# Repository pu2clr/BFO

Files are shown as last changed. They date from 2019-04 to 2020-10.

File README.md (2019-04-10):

# Simple BFO with si5351 controlled by Arduino

## Table of contents

1. [Introduction](https://github.com/pu2clr/BFO#introduction)
1. [Components](https://github.com/pu2clr/BFO#components)
1. [Schematic](https://github.com/pu2clr/BFO#this-bfo-interface)
1. [BFO interface](https://github.com/pu2clr/BFO#bfo-interface)
1. [Arduino pins and  Encoder, Step, Reset BFO and Turt On or Off commands](https://github.com/pu2clr/BFO#arduino-pins-and--encoder-step-reset-bfo-and-turn-on-or-off-commands)
1. [SI5351 Calibration](https://github.com/pu2clr/BFO#si5351-calibration)
1. [References](https://github.com/pu2clr/BFO#references)
1. [Videos about this project](https://github.com/pu2clr/BFO#videos-about-this-project)

## Introduction

The Si5351 is an I2C configurable clock generator that is very appropriate for receivers and transceivers projects in amateur radio applications. It is also suited for replacing crystal oscillators. It has three outputs that you can get three distinct frequencies at the same time. A great feature of the Si5351A is the possibility of using it with a microcontroller or platform like Arduino, PIC family and others. This small project is about a BFO that you can control the output of the Si5351A by using the Arduino Micro (Atmega32u4).  The BFO tested here ocilates from 452KHz to 458KHz. However, you can change this range for other between 8Kz to 160MHz. Click [here](https://youtu.be/AG9XZ8bdaNM) to watch a video about this BFO.

See also the similar project ["VFO and BFO with Si5351 and OLED,  controlled by Arduino (Micro)"](https://github.com/pu2clr/VFO_BFO_OLED_ARDUINO) 

### Using this BFO to listening to 15 meters ham radio station on USB mode

The first real test with this BFO project was made with a commercial radio that does not have SSB support. 

The Redsun RP-2100 is a multi-band commercial radio. It has no SSB internal support. However, it has an IF AM output that allows the user to connect a BFO or a Down-Converter (455 KHz to 12 KHz) to provide SSB, DRM and other modes. The photos bellow show the radio and BFO setup. You can also watch the video "[BFO with SI5351 and Arduino test with REDSUN RP2100](https://youtu.be/AG9XZ8bdaNM)".

#### Photo one
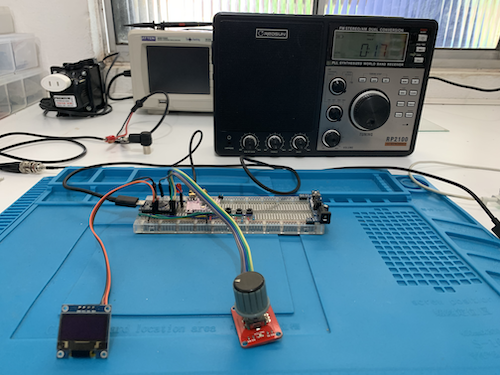
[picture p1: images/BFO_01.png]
Photo One


#### Photo two
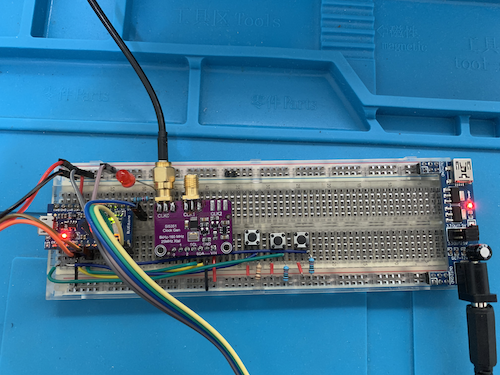
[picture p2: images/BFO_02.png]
Photo Two


#### Photo three
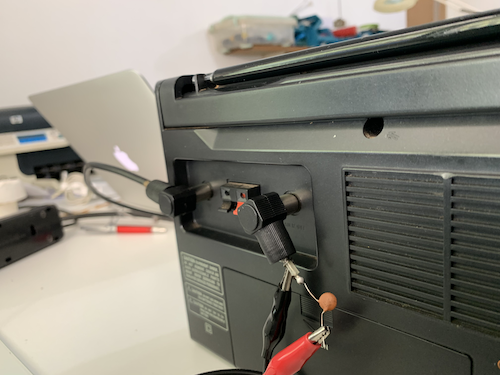
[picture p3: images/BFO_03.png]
Photo Three


## Components

- AZDelivery 1 x OLED Display Arduino 128 x 64 Pixels White 0.96 Inch I2C IIC Module for Arduino. This project uses the [Text only Arduino Library for SSD1306 OLED displays](https://github.com/greiman/SSD1306Ascii) Arduino library.
- Adafruit Si5351A Clock Generator Breakout Board - 8KHz to 160MHz. This project uses the [Si5351 Library for Arduino](https://github.com/etherkit/Si5351Arduino).
- One regular encoder.
- Three regular Push Button.
- Two 10nF ceramic capacitor
- Six 10K resistor
- One 1K resistor  
- Arduino Micro ([Atmega32u4](https://www.microchip.com/wwwproducts/en/ATmega32u4))

## BFO interface

The user can control the BFO  by using tow buttons and an encoder. 

- The __Step button__ changes the increment and decrement step. It can be 10Hz, 50Hz or 100Hz. The BFO can oscilate from 452KHz to 458KHz. You can change this range and frequency if necessary. 
- The __Reset VFO button__ sets the  BFO to central frequency (455KHz);
- The __Turn On/Off BFO button__  turns on or off the BFO. If it is pressed, alternates On and off. BFO off means no output signal.   

## Schematic

The schematic was built by using [Fritzing](http://fritzing.org/home/) Software, an open-source software tools to design circuits. See folder [schematic](https://github.com/pu2clr/BFO/tree/master/schematic).

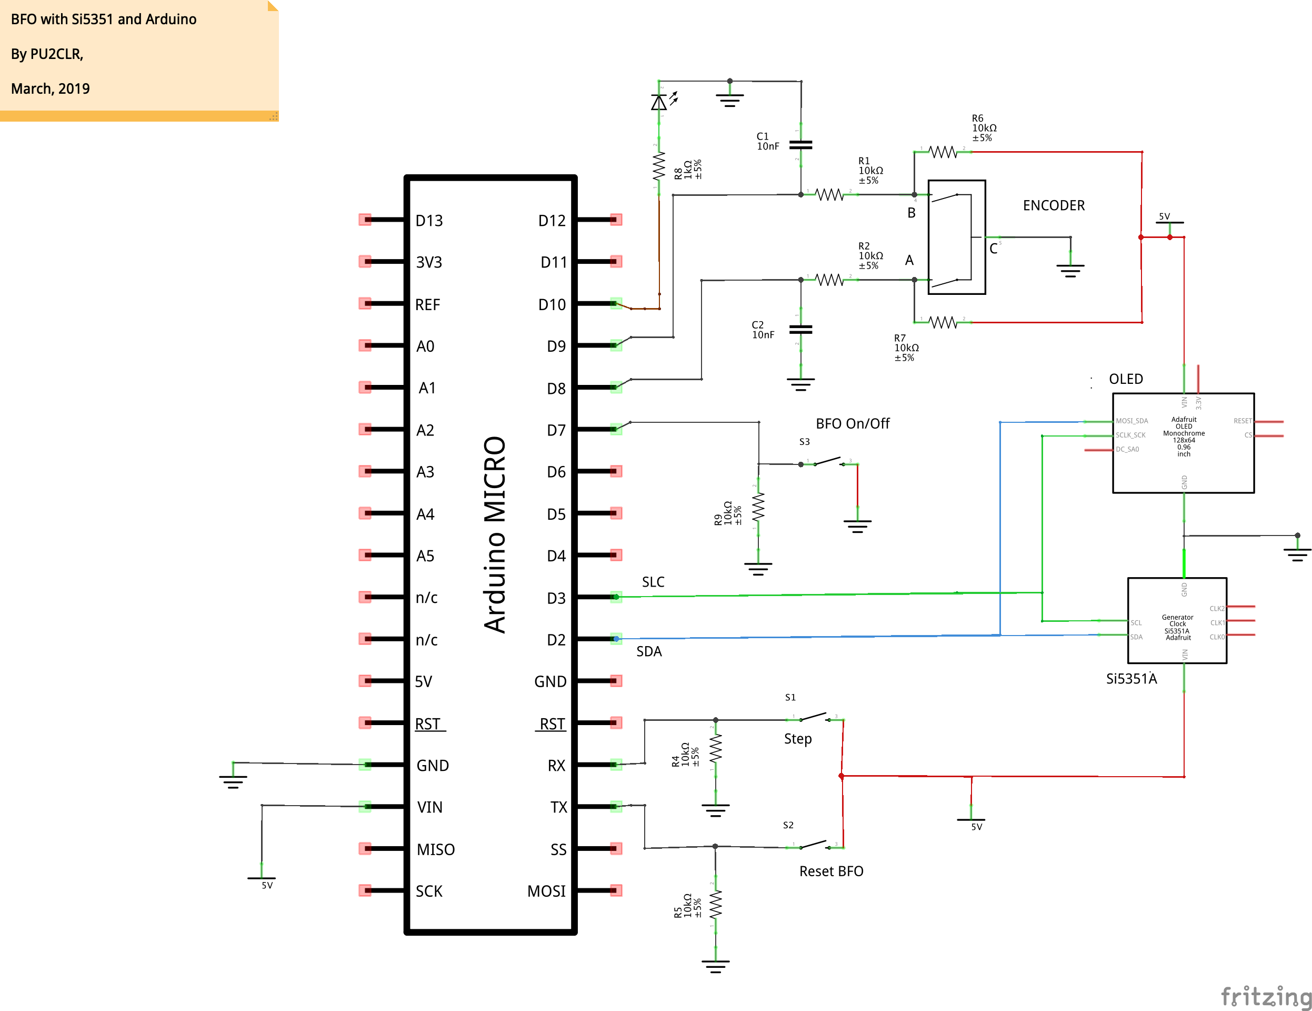
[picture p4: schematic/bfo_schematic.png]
BFO schematic
 

## Arduino pins and  Encoder, Step, Reset BFO and Turn On or Off commands

This section shows some aspects of the BFO [Arduino sketch](https://github.com/pu2clr/BFO/blob/master/source/si5351_bfo.ino) implementation. 

The pins for encoder and push buttons are defined bellow. If you need to change some push button pin, you should be aware that the push buttons are connected to  pins with external interrupts support. On Atmega32u4 you can use the pins 0,1,2,3 and 7, on 328-based (Nano, Mini, Uno) you can use the pins 2 and 3.

The short code below is part of the [Arduino sketch](https://github.com/pu2clr/BFO/blob/master/source/si5351_bfo.ino) and shows the enconder and push buttons setup.

```cpp
#define ENCODER_PIN_A 8 // Arduino  D8
#define ENCODER_PIN_B 9 // Arduino  D9

#define BUTTON_STEP 0   // Control the frequency increment and decrement
#define BUTTON_RST 1    // Set the frequency to central position
#define BUTTON_ON_OFF 7 // Turn BFO ON or OFF
```

The short code below shows the BFO frequency setup.

```cpp
// BFO range for this project is 4520KHz to 458KHz. The central frequency is 455KHz. 
#define MAX_BFO     45800000LU    // BFO max. frequency
#define CENTER_BFO  45500000LU    // BFO center frequency
#define MIN_BFO     45200000LU    // BFO min. frequency
```

The unit of frequency is 0.01Hz (1/100 Hz). See [Etherkit Library](https://github.com/etherkit/Si5351Arduino). 

You might need a different BFO frequency. If you want to modify the central frequency of BFO to 10MHz (for example), just change the lines below.

```cpp
#define MAX_BFO     1100000000LU   // BFO max. frequency (11MHz)
#define CENTER_BFO  1000000000LU   // BFO center frequency (10MHz)
#define MIN_BFO      990000000LU   // BFO min. frequency (9MHz)
```

The buttons were implemented by using Arduino interrupts resource. The code bellow shows it. 

```cpp
// Will stop what Arduino is doing call the function associated to the button
attachInterrupt(digitalPinToInterrupt(BUTTON_STEP), changeStep, RISING); // whenever the BUTTON_STEP is pressed call changeStep
attachInterrupt(digitalPinToInterrupt(BUTTON_RST), resetBfo, RISING);    // whenever the BUTTON_RST is pressed  call resetBfo
attachInterrupt(digitalPinToInterrupt(BUTTON_ON_OFF), bfoOnOff, RISING); // whenever the BUTTON_ON_OFF is pressed  call bfoOnOff
```

## SI5351 Calibration

You might need calibrate your si5351 to get more precision during signal generation. To do that you can use the si5351_calibration.ino sketch that comes with [the Si5351 library for Arduino](https://github.com/etherkit/Si5351Arduino). Click [here](https://github.com/etherkit/Si5351Arduino#calibration) to see more about si5351 calibration. You can also try watch [this Portuguese video](https://youtu.be/BJ83uvDcfIo) that show how to calibrate the si5351. Another video about si5351 calibration can be watch [here (Homebrew 80/40m SSB/CW Rig - #7a Si5351 Calibration)](https://youtu.be/fJ_3z2IAjKg).

The line code bellow shows the correction factor found during this project. 

```cpp
// Change this value bellow  (CORRECTION_FACTOR) to 0 if you do not know the correction factor of your Si5351A.
#define CORRECTION_FACTOR 80000 // See how to calibrate your Si5351A (0 if you do not want).
```

if you do not want calibrate, set CORRECTION_FACTOR to 0 as shown bellow. 

```cpp
#define CORRECTION_FACTOR 0 
```

## References

- [Arduino](https://www.arduino.cc)
- [Arduino Micro Pinout](http://pinoutguide.com/Electronics/arduino_micro_pinout.shtml)
- [Atmega32u4](https://www.microchip.com/wwwproducts/en/ATmega32u4)
- [Arduino Interrupts](https://www.arduino.cc/reference/en/language/functions/interrupts/interrupts/)
- [Text only Arduino Library for SSD1306 OLED displays](https://github.com/greiman/SSD1306Ascii)
- [Si5351 Library for Arduino](https://github.com/etherkit/Si5351Arduino)
- [Si5351 calibration](https://github.com/etherkit/Si5351Arduino#calibration)
- [Fritzing](http://fritzing.org/home/)
- [My ham radio Facebook](https://www.facebook.com/PU2CLR)
- [QRZ - Biografy and my ham radio page](https://www.qrz.com/db/PU2CLR)

## Videos about this project

- [BFO with SI5351 and Arduino test with REDSUN RP2100](https://youtu.be/AG9XZ8bdaNM)
- [VFO and BFO with Si5351A controlled by Arduino](https://youtu.be/pFDvcIk5EAk)
- [VFO e BFO com Si5351A e Arduino - Calibração do Si5351](https://youtu.be/BJ83uvDcfIo)
- [VFO e BFO com o Si5351 e OLED controlado por Arduino - (Portuguese)](https://youtu.be/0sGL2KpOJH4)
- [Homebrew 80/40m SSB/CW Rig - #7a Si5351 Calibration](https://youtu.be/fJ_3z2IAjKg).

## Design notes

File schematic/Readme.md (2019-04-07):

# The Arduino and components wire up.

This schematic was made by using the [Fritzing Software](http://fritzing.org/home/)">

## Schematic

 BFO schematic

### Si5351A

The __Si5351A__ is connected to D2 (SDA) and  D3 (SCL).

### OLED Display SSD1306 - 128 x 64/0.96

The __OLED__ is connected to D2 (SDA) and  D3 (SCL). Yes, the same Si5351A connections.

### Encoder

Connect Arduino __D8__ and __D9__ pins to the __Encoder__ pin __A__ and pin __B__ respectively.

### Push Button Step

Connect Arduino __D1/Tx__ pin to the __Step__ push button (S1). 

### Reset VFO

Connect Arduino __D0__ pin to the __Reset BFO__ push button (S2).

### BFO On/OFF 

Connect the Arduino pin __D7__ to the BFO On/Off push button  (S3).

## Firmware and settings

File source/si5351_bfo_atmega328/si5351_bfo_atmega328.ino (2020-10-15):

/*
  NOT TESTED 
  Program to control the "Adafruit Si5351A Clock Generator" or similar via Arduino.
 
  BFO controlled by Arduino 
  
  See on https://github.com/etherkit/Si5351Arduino  and know how to calibrate your Si5351
  See also the example Etherkit/si5251_calibration
  Author: Ricardo Lima Caratti (PU2CLR) -   2019/03/07
*/

#include <si5351.h>
#include <Wire.h>
#include "SSD1306Ascii.h"
#include "SSD1306AsciiAvrI2c.h"

// Enconder PINs
#define ENCODER_PIN_A 8 // 
#define ENCODER_PIN_B 9 // 

// OLED Diaplay constants
#define I2C_ADDRESS 0x3C
#define RST_PIN -1 // Define proper RST_PIN if required.

// Change this value bellow  (CORRECTION_FACTOR) to 0 if you do not know the correction factor of your Si5351A.
#define CORRECTION_FACTOR 80000 // See how to calibrate your Si5351A (0 if you do not want).

#define BUTTON_STEP 2   // Control the frequency increment and decrement
#define BUTTON_ON_OFF 3 // Turn BFO ON or OFF

// BFO range for this project is 452KHz to 458KHz. The central frequency is 455KHz.
#define MAX_BFO 45800000LU    // BFO max. frequency
#define CENTER_BFO 45500000LU // BFO center frequency
#define MIN_BFO 45200000LU    // BFO min. frequency

#define STATUS_LED 10 // Arduino status LED Pin 10
#define STATUSLED(ON_OFF) digitalWrite(STATUS_LED, ON_OFF)
#define MIN_ELAPSED_TIME 300
#define MIN_ENCODE_ELAPSED 5 // min delay to procces next encoder action

// OLED - Declaration for a SSD1306 display connected to I2C (SDA, SCL pins)
SSD1306AsciiAvrI2c display;

// The Si5351 instance.
Si5351 si5351;

// Struct for step database
typedef struct
{
  char *name; // step label: 50Hz, 10Hz, 500Hz and 100KHz
  long value; // Frequency value (unit 0.01Hz See documentation) to increment or decrement
} Step;

// Steps database. You can change the Steps and numbers of steps here if you need.
Step step[] = {
    {(char *) "10Hz  ", 1000}, // Minimum Frequency step (incremente or decrement) 10Hz
    {(char *) "50Hz  ", 5000},
    {(char *) "100Hz  ", 10000}}; // Maximum frequency step 100Hz
// Calculate the index of last position of step[] array
const int lastStepBFO = (sizeof step / sizeof(Step)) - 1;
volatile long currentStep = 0;

volatile boolean isFreqChanged = true;
volatile boolean clearDisplay = false;

volatile uint64_t bfoFreq    = CENTER_BFO; // 455 KHz for this project
volatile uint64_t bfoLastValue;            // will save the bfoFreq before turn BFO off

volatile uint8_t bfoOn = 1; // If 1 then BFO is enable, 0 disable
volatile boolean isBfoOnOff = false;

long volatile elapsedTimeInterrupt = millis(); // will control the minimum time to process an interrupt action
long elapsedTimeEncoder = millis();

// Encoder variable control
unsigned char encoder_pin_a;
unsigned char encoder_prev = 0;
unsigned char encoder_pin_b;

void setup()
{
  // LED Pin
  pinMode(STATUS_LED, OUTPUT);
  // Encoder pins
  pinMode(ENCODER_PIN_A, INPUT);
  pinMode(ENCODER_PIN_B, INPUT);
  // Si5351 contrtolers pins

  pinMode(BUTTON_STEP, INPUT);

  // The sistem is alive
  blinkLed(100);
  STATUSLED(LOW);
  // Initiating the OLED Display
  display.begin(&Adafruit128x64, I2C_ADDRESS);
  display.setFont(Adafruit5x7);
  display.set2X();
  display.clear();
  display.print("\nBFO TEST");
  display.print("\n\nBY PU2CLR");

  delay(3000);
  display.clear();
  displayDial();
  // Initiating the Signal Generator (si5351)
  si5351.init(SI5351_CRYSTAL_LOAD_8PF, 0, 0);
  // Adjusting the frequency (see how to calibrate the Si5351 - example si5351_calibration.ino)
  si5351.set_correction(CORRECTION_FACTOR, SI5351_PLL_INPUT_XO);
  si5351.set_pll(SI5351_PLL_FIXED, SI5351_PLLA);
  si5351.set_freq(bfoFreq, SI5351_CLK0); // Start CLK0 (VFO)

  // Disable CLK 1 and 2 outputs
  si5351.output_enable(SI5351_CLK1, 0);
  si5351.output_enable(SI5351_CLK2, 0);
  
  si5351.update_status();
  // Show the initial system information
  delay(500);

  // Will stop what Arduino is doing call the function associated to the button
  attachInterrupt(digitalPinToInterrupt(BUTTON_STEP), changeStep, RISING); // whenever the BUTTON_STEP is pressed call changeStep
  attachInterrupt(digitalPinToInterrupt(BUTTON_ON_OFF), bfoOnOff, RISING); // whenever the BUTTON_ON_OFF is pressed  call bfoOnOff

  delay(1000);
}

// Blink the STATUS LED
void blinkLed(int blinkDelay)
{
  for (int i = 0; i < 5; i++)
  {
    STATUSLED(HIGH);
    delay(blinkDelay);
    STATUSLED(LOW);
    delay(blinkDelay);
  }
}

// Show Signal Generator Information
// Verificar setCursor() em https://github.com/greiman/SSD1306Ascii/issues/53
void displayDial()
{
  double bfo = bfoFreq / 100000.0;

  // display.setCursor(0,0)
  // display.clear();
  display.set2X();
  display.setCursor(0, 0);
  display.print(" ");
  display.print(bfo);
  display.print(" KHz");

  display.print("\n\nStep: ");
  display.print(step[currentStep].name);

  display.set1X();
  display.print("\n\nBFO is ");
  display.print((bfoOn) ? "On" : "Off");
}

// Change the frequency (increment or decrement)
// direction parameter is 1 (clockwise) or -1 (counter-clockwise)
void changeFreq(int direction)
{
  bfoFreq += step[currentStep].value * direction; // currentStep * direction;
  // Check the BFO limits
  if (bfoFreq > MAX_BFO || bfoFreq < MIN_BFO) // BFO goes to center if it is out of the limits
  {
    bfoFreq = CENTER_BFO;     // Go to center
    blinkLed(50); // Alert the user that the range is over
  }
  isFreqChanged = true;
}

// Change frequency increment rate
void changeStep()
{
  if ((millis() - elapsedTimeInterrupt) < MIN_ELAPSED_TIME)
    return;       // nothing to do if the time less than MIN_ELAPSED_TIME milisecounds
  noInterrupts(); // disable interrupts
  currentStep = (currentStep < lastStepBFO) ? (currentStep + 1) : 0;
  isFreqChanged = true;
  clearDisplay = true;
  elapsedTimeInterrupt = millis();
  interrupts(); // enable interrupts
}

void bfoOnOff()
{
  if ((millis() - elapsedTimeInterrupt) < MIN_ELAPSED_TIME)
    return;       // nothing to do if the time less than MIN_ELAPSED_TIME milisecounds
  noInterrupts(); // disable interrupts

  // If BFO is On it becomes Off. If BFO is Off it becomes On
 
  bfoOn = !bfoOn;

  bfoFreq = (bfoOn) ? bfoLastValue : 0;
  isBfoOnOff = true;

  isFreqChanged = true;
  clearDisplay = true;

  elapsedTimeInterrupt = millis();
  interrupts(); // enable interrupts
}

// main loop
void loop()
{
  if (bfoOn) // porcess just if BFO is on
  {
    // Next enconder action only can be processed after MIN_ENCODE_ELAPSED (5) milisecounds
    if ((millis() - elapsedTimeEncoder) > MIN_ENCODE_ELAPSED)
    {
      encoder_pin_a = digitalRead(ENCODER_PIN_A);
      encoder_pin_b = digitalRead(ENCODER_PIN_B);
      if ((!encoder_pin_a) && (encoder_prev)) // has ENCODER_PIN_A gone from high to low?
      {                                       // if so,  check ENCODER_PIN_B. It is high then clockwise (1) else counter-clockwise (-1)
        changeFreq(((encoder_pin_b) ? 1 : -1));
      }
      encoder_prev = encoder_pin_a;
      elapsedTimeEncoder = millis(); // keep elapsedTimeEncoder updated
    }
    // check if some action changed the frequency
    if (isFreqChanged)
    {
      if (isBfoOnOff) // if the user turn off the BFO (by pressing the On OFF button)
      {
        si5351.output_enable(SI5351_CLK0, bfoOn); // Stop gereneting signal if bfoOn is 0 or start genereting if it is 1
        isBfoOnOff = false;                       // Reset the BUTTON_ON_OFF status (not pressed)
      }
      else
      {
        bfoLastValue = bfoFreq;
        si5351.set_freq(bfoFreq, SI5351_CLK0);
      }
      isFreqChanged = false;
      displayDial();
    }
    else if (clearDisplay)
    {
      display.clear();
      displayDial();
      clearDisplay = false;
    }
  }
}
